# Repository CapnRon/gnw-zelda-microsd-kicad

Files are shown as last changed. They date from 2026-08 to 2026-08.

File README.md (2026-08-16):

# GnW-Zelda-MicroSD

A castellated-edge microSD interposer for the Game & Watch: The Legend of
Zelda console mod scene -- built as original KiCad artwork, informed by
existing community Gerber-only releases rather than copied from any of
them.

The board mates directly to the console's STM32 mainboard via a
7-position castellated edge (real 0.3x1.2mm SMD pad geometry, machined
flush by the board-edge mill -- this is the critical mechanical/electrical
mating surface, not an approximation) and carries an onboard RT9193-28GB
LDO regulating the console's raw ~4.2V battery rail down to a safe 2.8V
for the microSD card.

**This is a flex PCB**, not rigid: 2-layer, 1oz copper both sides on a
2mil (50.8um) polyimide core, 0.1408mm total board thickness.

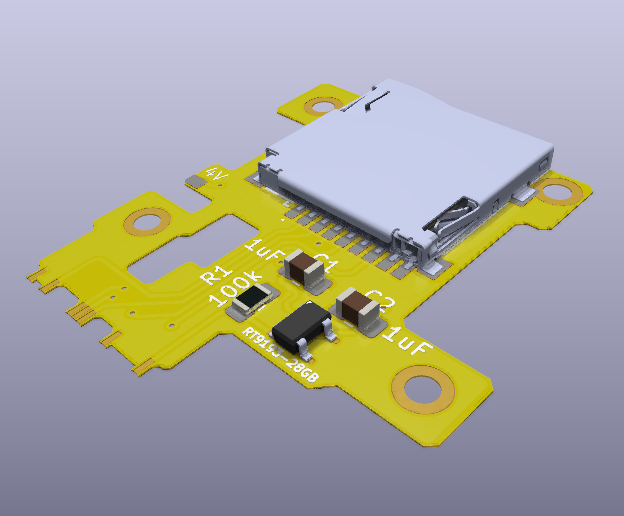
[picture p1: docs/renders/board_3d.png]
Populated board, 3D render


## Status

Working draft, not yet fab-verified on real hardware. Electrically clean
(0 unconnected nets, 0 shorts per `kicad-cli pcb drc`) with real routing
and filled ground pours on both copper layers. Remaining DRC output is
DFM-grade (clearances, drill sizes, silk overlap) -- normal manual-review
territory before ordering boards, not electrical faults. See
`docs/design-notes.md` for the full derivation, findings, and everything
still worth double-checking by hand in the KiCad GUI before fabrication.

## Commit history

- **Initial commit** -- the original reconstruction: schematic, PCB,
  footprints, and silkscreen rebuilt from scratch in KiCad from measured
  Gerber geometry (see Origin and attribution below). No third-party
  KiCad source files were used at this point -- every footprint was
  RE'd/approximated by hand from pad positions and sizes read off the
  Gerbers.
- **This commit** -- incorporates real assets from PrimoAngelo's native
  KiCad source (added as source material in the prior commit) now that
  he's confirmed as the known-good original author: J2 (microSD socket)
  and J3 (VBAT tab) were swapped from their RE'd/approximated footprints
  to his real `MSD1A`/`Pad_1x1_5` pad geometry, and a real STEP model was
  wired into U1 (RT9193 LDO). C1/C2/R1 now carry a second, real
  hand-solder-0805 footprint stacked at the same location as their
  original passive footprint, so either package size can be assembled.
  Also fixed a schematic/PCB reference-designator mismatch (J2/J3 and
  U1/U2 were swapped between the two files) and a batch of inconsistent
  net names left over from re-syncing the PCB against the schematic.

## Repository layout

```
hardware/         KiCad project (open GnW-Zelda-MicroSD.kicad_pro here)
production/       Gerbers + drill files (RS-274X, Excellon) + a zipped bundle
docs/             Design notes, top/bottom copper + 3D renders
source-material/  Original third-party source files this design descends
                   from, preserved for attribution/licence compliance --
                   see source-material/README.md
LICENSE           CERN-OHL-S v2 full text
NOTICE.md         Licensing rationale and attribution summary
```

## Circuit

- **U1** -- RT9193-28GB LDO. VIN <- raw battery (~4.2V) via the J1
  castellated edge; EN <- console GPIO (via J1); VOUT -> 2.8V microSD
  supply.
- **J2** -- microSD socket (SPI-mode wiring: CS/MOSI/MISO/CLK + VDD/GND),
  PrimoAngelo's real `MSD1A` footprint.
- **J1** -- 7-position castellated edge: GND, CS, MISO, CLK, MOSI, NC
  (spare), EN.
- **J3** -- castellated VBAT solder tab, PrimoAngelo's real `Pad_1x1_5`
  footprint (same machined-edge technique as J1) -- solders directly to
  the positive terminal of an external SMD capacitor.
- **R1** -- 100k pulldown holding the LDO disabled by default until the
  console GPIO actively enables it. Real hand-solder-0805 footprint
  stacked at the same location as the original RE'd footprint.
- **C1/C2** -- input/output decoupling for U1. Same dual-footprint
  stacking as R1 (0805 hand-solder on top of the original).
- **H1-H4** -- plated, electrically-isolated mounting pads (3.0mm pad /
  1.8mm drill), positioned to match the reference designs' mounting
  pattern.

## Origin and attribution

This design was reconstructed from precise geometry (board outline, pad
positions/sizes, net connectivity, and real copper routing) extracted
directly from Gerber-only community releases for the same G&W Zelda
microSD mod, tracing back through three generations of prior work:

- **Tim Schuerewegen** originated the project.
- **Hundshamer** picked it up and pushed it forward to its final form,
  `GNW-MICROSDx1-ZELDA-V3.4`. Used during reconstruction for
  cross-validation (confirmed identical castellated pinout via a
  different edge-connector pin-numbering scheme than PrimoAngelo's
  release) and as the source for the drilled-via castellation technique
  referenced during development.
- **PrimoAngelo** began his own work from Hundshamer's v3.4 design,
  producing `MicroSD_Zelda_FORO_JLC_FIX_V2 - NO_LOGO`, credited to him in
  its own back-silkscreen (visible in the source Gerbers). This is the
  primary geometric basis for this repo's outline, placement, and
  routing.

Everything in this repository (schematic, PCB, footprints, silkscreen)
was rebuilt from scratch in KiCad from measured geometry, not copied.
This reconstruction was completed before any contact with any of the
above. Afterward, both PrimoAngelo and Hundshamer were reached directly:
PrimoAngelo confirmed authorship and provided native KiCad source for
this design and a sibling Mario board; Hundshamer confirmed the lineage
back to Schuerewegen's original project in a friendly exchange, but had
no additional source material to contribute beyond what was already used
above. All original source material received is preserved under
`source-material/` for full provenance and CERN-OHL-S v2 compliance; see
`source-material/README.md` for the complete attribution chain and
`NOTICE.md` for the licensing rationale. Full credit to the original
designers for the mod itself; if you're one of them and want anything
here changed or removed, open an issue.

## License

CERN-OHL-S v2 (CERN Open Hardware Licence Version 2 - Strongly
Reciprocal). See [LICENSE](LICENSE) and [NOTICE.md](NOTICE.md).

## Building / opening

Requires KiCad 10. Open `hardware/GnW-Zelda-MicroSD.kicad_pro`.

Most custom parts (castellated connectors, exact-geometry footprints for
the LDO/passives) are embedded directly in the `.kicad_pcb`. J2 and J3
now use real footprints from PrimoAngelo's native library, referenced via
project-scoped libraries in `hardware/fp-lib-table` that point into
`source-material/` with `${KIPRJMOD}`-relative paths -- so the project
stays portable to any clone location, but `source-material/` must come
along with it. The schematic symbol library
(`hardware/gnw_zelda_microsd.kicad_sym`) is referenced the same way.

## Before ordering boards

- This is a hand-routed/reconstructed draft -- give it a real pass in the
  KiCad GUI (visual DRC review, silk/courtyard cleanup) before sending to
  a fab.
- The castellated edge geometry is the one dimension that matters most:
  verify pad pitch/size against your actual console board before
  committing to a fab run.
- No BOM/pick-and-place export included yet -- add before ordering
  assembly.

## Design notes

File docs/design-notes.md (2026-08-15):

# Design notes

## Goal

Build original KiCad artwork for a G&W Zelda microSD mod interposer,
using two existing Gerber-only community releases as dimensional/circuit
reference (not to be copied wholesale) -- see README for attribution.

## Reverse-engineering methodology

Both source projects are Gerber+drill exports only, no native KiCad
project files. Everything used here was extracted directly from the raw
RS-274X/Excellon data:

- **Board outline**: parsed all `D01`/`D02` draw commands from
  `*-Edge_Cuts.gbr`, chained line/arc segments into closed loops by
  matching endpoint coordinates (tolerance ~0.02mm). The
  `MicroSD_Zelda_FORO_JLC_FIX_V2` source outline resolved to two loops --
  the main board profile (81 segments) and a separate ~4x8mm cutout
  (15 segments) that turned out to be a real hole in the board, not a
  microSD card slot as first assumed.
- **Component placement & pinout**: KiCad's Gerber X2 export embeds
  `%TO.P,<ref>,<pin>,<name>%` and `%TO.N,<netname>%` attributes on every
  pad flash. Parsed these directly to get exact pad positions AND their
  real net/pin names -- no guessing required for pinout mapping.
- **Real pad geometry**: matched each pad flash to its active Gerber
  aperture (`%ADD..%` definitions) to get true pad shapes/sizes, rather
  than assuming standard library footprint dimensions. This caught a real
  early mistake -- initial footprints used guessed sizes (e.g. 0.7x0.5mm
  for the microSD socket signal pads) that were significantly smaller
  than the source's real 0.7x1.6mm pads.
- **Routing**: built a graph from every `F_Cu`/`B_Cu` trace segment
  (nodes = endpoints within ~0.02mm, edges = segments with their real
  layer/width), then ran Dijkstra between each net's known pad endpoints
  to extract the actual routed path -- including real F.Cu/B.Cu layer
  transitions -- rather than inventing new routing from scratch.

## The castellated edge (critical dimension)

The J1 connector butts directly against the console's STM32 mainboard --
this is the one piece of geometry that has to be exactly right, since a
wrong pitch/size means the board simply doesn't mate.

Confirmed via aperture lookup: **0.3mm x 1.2mm rectangular SMD pads**
(Gerber aperture `R,0.300000X1.200000`), each pad centered ~0.55mm in
from the true board edge so it slightly overhangs and gets milled flush
during fabrication -- this is the standard "castellated by copper
overhang" technique (as opposed to the alternative drilled-via
castellation method used by the other reference design, `GNW-MICROSDx1-
ZELDA-V3.4`, which drills a small via exactly on the edge line and relies
on the edge mill to bisect it).

7 contacts, confirmed identical function across both independently-
authored source designs (different edge-connector pin-numbering schemes,
same signals): **GND, CS, MISO, CLK, MOSI, NC (spare), EN**.

## J3: not a through-hole pad

Initially modeled J3 (the VBAT tap) as a simple 1mm through-hole point for
hand-soldering a flying lead. This was wrong. Its net auto-name in the
source Gerber (`Net-(J8-Pin_1)`) revealed it's actually an **8th
castellated contact** whose reference designator was stripped when the
source file was sanitized for public release (filename literally says
"NO_LOGO"). Confirmed via aperture lookup (`R,1.500000X1.500000`, a
1.5x1.5mm square pad) and via position -- it sits right at the board's
left edge with the same small mill-overhang pattern as the J1 contacts.
Rebuilt as a castellated square pad; per the design intent, it's meant to
solder directly to the positive terminal of an external SMD capacitor.

## Ground pour: the "covers everything until refilled" bug

`kicad-cli pcb export gerbers --check-zones` fills zones **transiently**
for that one export -- it never writes the computed fill back into the
`.kicad_pcb` file. Every earlier draft had a `(zone ...)` block with no
`filled_polygon` data at all, so opening the file fresh (or running DRC
without that flag) showed zero actual GND copper -- explaining a batch of
phantom "unconnected" ratsnest warnings that had nothing to do with the
routing itself.

Fixed by computing the fill directly (Shapely: zone boundary ∩ board
outline, minus every foreign-net pad/trace/via buffered by clearance) and
writing real `filled_polygon` data into both zone blocks. First attempt
at this had its own bug: a polygon with a hole (the board's real cutout,
see above) was emitted as two separate additive `filled_polygon` entries
-- an outer shape plus the hole's own boundary as a *second* filled shape
-- which paints solid copper right back over the hole instead of
excluding it. Fixed with the standard "keyhole" technique: cut a thin
slit from the hole out to the exterior boundary so the whole island is
one simple, hole-free ring.

## Routing bugs found during review

- A via for one net (VBAT_4V2) physically overlapped a crossing trace
  from a different net (SPI_CLK) on the same layer -- a real short. Root
  cause: two separately-computed net paths shared the same physical trunk
  (one was a redundant subset of the other); dropping the redundant path
  removed the overlapping via entirely.
- Missing vias at real F.Cu/B.Cu layer transitions, caused by not
  correctly tracking which endpoint was the true shared connection point
  between consecutive segments in a reversed-order path reconstruction
  (Dijkstra's predecessor-walk produces the path back-to-front).
- Explicit point-to-point GND traces were redundant once both layers had
  a real filled pour (every GND pad is F.Cu-only, so the F.Cu pour alone
  already connects them) -- removed entirely in favor of 1-2 stitching
  vias tying the two pours together, and verified those vias actually
  land inside real board copper (an earlier stitching via placement
  landed 0.93mm outside the true board outline -- "floating in space").

## Verification

`kicad-cli pcb drc` (KiCad 10.0.4, not the system default 9.0.8 --
version mismatch between the two installed CLIs caused a "Failed to load
board" red herring early on) confirms 0 unconnected items and 0
shorting_items on the current revision. Remaining ~46 violations are
DFM-grade (clearances, drill sizing, silk overlap) -- normal manual
cleanup, not electrical faults.

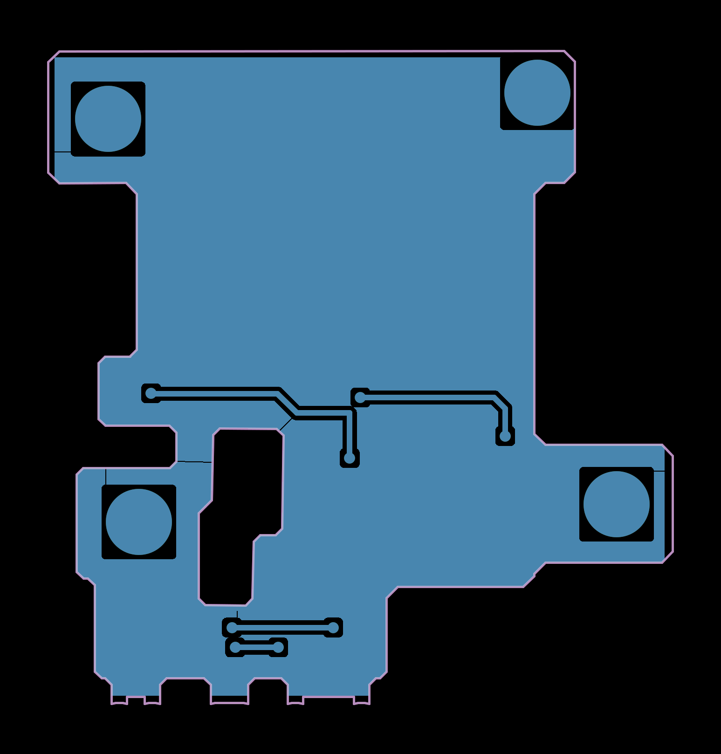
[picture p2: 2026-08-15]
docs/renders/bottom_copper.png

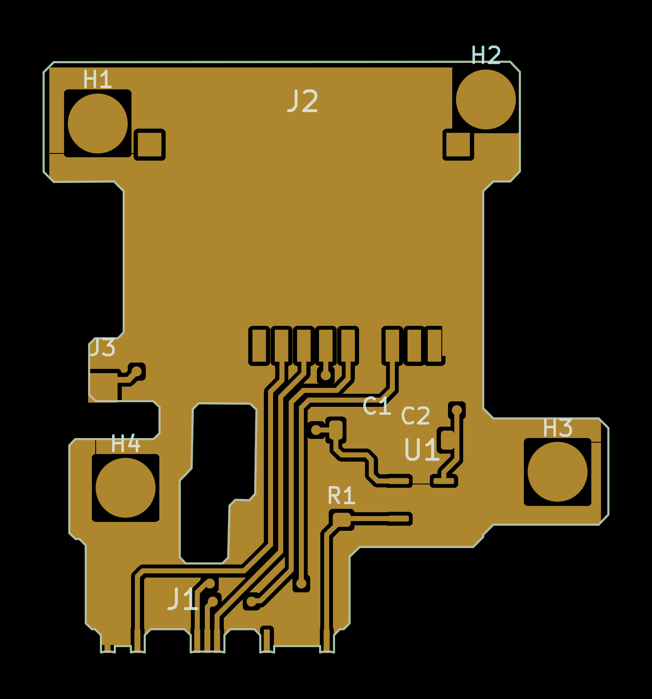
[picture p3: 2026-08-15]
docs/renders/top_copper.png

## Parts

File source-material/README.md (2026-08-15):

# Source material

This directory preserves, unmodified, every original design file this
project's attribution chain depends on -- kept here for provenance and
CERN-OHL-S v2 licence compliance (Covered Source must be made available;
see the repository [LICENSE](../LICENSE) and [NOTICE.md](../NOTICE.md)).

Each subdirectory contains the original archive exactly as received
(`*.zip`) plus its extracted contents (`extracted/`) for easier browsing
and diffing.

## Attribution chain

1. **Tim Schuerewegen** originated the Game & Watch Zelda microSD mod
   project this whole lineage descends from.
2. **Hundshamer** picked up the project and pushed it forward to its
   final form, `GNW-MICROSDx1-ZELDA-V3.4` -- see
   `gnw-microsd-zelda-v3.4-hundshamer/`.
3. **PrimoAngelo** began his own work from Hundshamer's v3.4 design,
   producing a derivative/alternate release -- see
   `microsd-zelda-gerbers-primoangelo/` (the Gerber-only file this
   repository was reverse-engineered from) and `kicad-zelda-primoangelo/`
   (PrimoAngelo's own native KiCad source for the same design, obtained
   later).
4. **This repository** was reverse-engineered from PrimoAngelo's
   Gerber-only release, then cross-validated against Hundshamer's v3.4
   design, before any contact with any of the above.

After that reconstruction was complete, both PrimoAngelo and Hundshamer
were contacted directly. PrimoAngelo confirmed authorship and provided
native KiCad source for this design and a sibling Mario board (see
below). Hundshamer confirmed the lineage back to Schuerewegen's original
project in a friendly exchange, but had no additional source material to
contribute beyond `GNW-MICROSDx1-ZELDA-V3.4`, already included here.

## `gnw-microsd-zelda-v3.4-hundshamer/`

`GnW_SD_v2.zip`, containing `GNW-MICROSDx1-ZELDA-V3.4` -- a Gerber/
Excellon-only release by **Hundshamer**, who picked up Tim Schuerewegen's
original Game & Watch Zelda microSD mod project and pushed it forward to
this, its final v3.4 form. Used during the original reverse-engineering
work for cross-validation (it confirmed the castellated pinout via a
different edge-connector pin-numbering scheme than PrimoAngelo's release)
and as the source for the drilled-via castellation technique referenced
in `docs/design-notes.md`.

## `microsd-zelda-gerbers-primoangelo/`

`MicroSD_Zelda_Final.zip`, containing
`MicroSD_Zelda_FORO_JLC_FIX_V2 - NO_LOGO` -- a Gerber/Excellon-only
release (no native KiCad project) credited to **PrimoAngelo** in its own
back-silkscreen, who began his own work from Hundshamer's v3.4 design
above. This is the file this repository's design was originally
reverse-engineered from, before any contact with any of the original
designers -- see `docs/design-notes.md` for the full reverse-engineering
methodology.

## `kicad-zelda-primoangelo/`

`KICAD_ZELDA_PrimoAngelo.zip`, containing the native KiCad project
(`MicroSD_Zelda_FORO_JLC_FIX_V2.kicad_pcb`/`.kicad_pro`) for the same
design above. Provided directly by PrimoAngelo **after** this
repository's reverse-engineering work was already complete, when the
designer was contacted for permission/attribution. Included here for full
provenance and licence compliance; this repository's own KiCad files were
not re-derived from it, since the reconstruction from Gerbers was already
finished and independently verified by the time this arrived.

## `kicad-mario-primoangelo/`

`KICAD_MARIO_PrimoAngelo.zip`, containing a native KiCad project
(`MicroSD_Mario_JLC_FIX_V3.kicad_pcb`/`.kicad_pro`) for a sibling
microSD mod board for a different Game & Watch title (Super Mario Bros.),
also by PrimoAngelo. Provided for the same reason as above, during the
same contact. Not a source for this repository's Zelda board -- included
purely for attribution/provenance and as reference material for anyone
working on the Mario variant in the future.

## `kicad-libs-primoangelo/`

`Libs.zip`, containing PrimoAngelo's own native KiCad footprint libraries
and 3D models used to build the designs above: `Impronte/` ("footprints",
Italian) with `Pad.pretty`/`_FG_Pad.pretty` (the castellated edge-contact
footprints, including `Pad_0_3x1_2.kicad_mod` -- matching this
repository's own independently-reconstructed 0.3x1.2mm castellated pad
geometry exactly, real confirmation the original reverse-engineering in
`docs/design-notes.md` got the geometry right) and `_FG_MicroSD.pretty`
(microSD socket/connector footprints), plus `Modelli_3D/` ("3D models")
with STEP models for the microSD socket and connector. Provided by
PrimoAngelo in a later contact, for the same attribution/provenance
reason as the items above -- not used to modify this repository's
existing (already-verified) footprints, included for completeness and as
a resource for future work (e.g. 3D visualization, mechanical checks).

## Licensing note

These files are third-party work, included here under the terms of
CERN-OHL-S v2 (the licence this repository itself is released under --
see [NOTICE.md](../NOTICE.md)). They are not covered by this repository's
own attribution disclaimers in `README.md`; refer to the original
designers for any use beyond what CERN-OHL-S v2 permits.

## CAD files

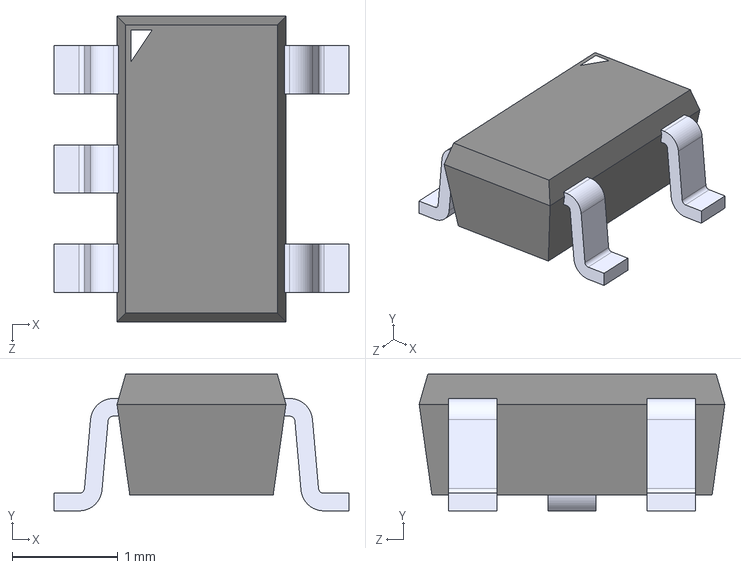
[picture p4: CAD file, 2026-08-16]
hardware/RT919333GB.STEP
2.79 x 1.30 x 2.90 mm

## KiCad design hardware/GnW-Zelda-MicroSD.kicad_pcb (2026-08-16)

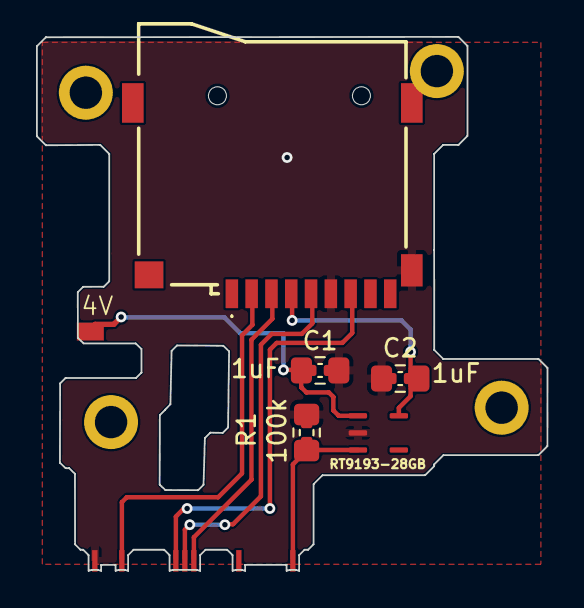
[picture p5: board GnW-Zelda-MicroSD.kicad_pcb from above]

Board: 2 copper layers, 28.4 x 29.7 mm, 11 parts (0 on the bottom side), 8 nets.

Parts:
C1, C2: 1uF; C_0402_1005Metric
H1, H2, H3, H4: MountingHole_3.0mm; MountingHole_Plated
J1: Castellated_Edge_7P
J2: MicroSD_Socket_TFP09; MSD1A
J3: Battery_Tap_2P; Pad_1x1_5
R1: 100k; R_0402_1005Metric
RT9193-28GB: RT9193-28GB; RT9193_exact

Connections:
EN_PA15: J1.7 (EN), R1.1, RT9193-28GB.3 (EN)
GND: C1.2, C2.2, J1.1 (GND), J2.6 (GND), J2.10 (SHIELD_GND), R1.2, RT9193-28GB.2 (GND)
SPI_CLK: J1.4 (CLK), J2.5 (SCLK)
SPI_CS: J1.2 (CS), J2.2 (CS)
SPI_MISO: J1.3 (MISO), J2.7 (DO)
SPI_MOSI: J1.5 (MOSI), J2.3 (DI)
VBAT_4V2: C1.1, J3.1 (VBAT_1), RT9193-28GB.1 (VIN)
VDD_SD_2V8: C2.1, J2.4 (VDD), RT9193-28GB.5 (VOUT)

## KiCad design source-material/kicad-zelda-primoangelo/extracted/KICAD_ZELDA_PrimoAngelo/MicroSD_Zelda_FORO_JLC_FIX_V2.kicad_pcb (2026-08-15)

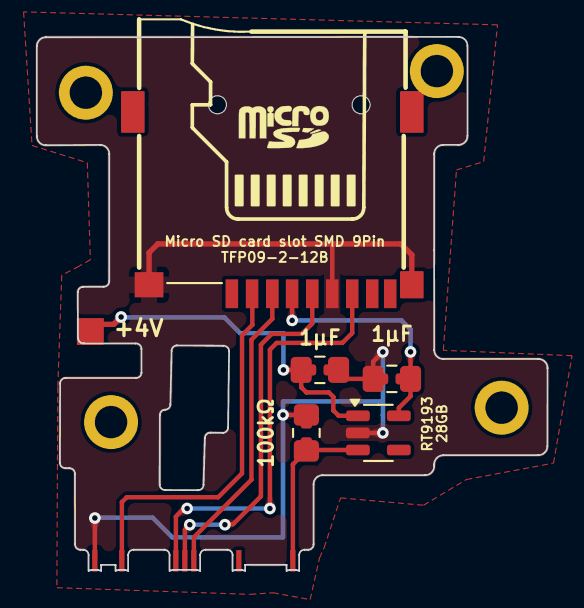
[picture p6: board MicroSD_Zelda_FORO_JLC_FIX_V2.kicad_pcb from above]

Board: 2 copper layers, 28.4 x 29.7 mm, 21 parts (1 on the bottom side), 8 nets.

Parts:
1µF, 1µF#2: 1u; C_0402_1005Metric_Pad0.74x0.62mm_HandSolder
100kΩ: 100k; R_0402_1005Metric_Pad0.72x0.64mm_HandSolder
C2, C4: 1u; C_0805_2012Metric_Pad1.18x1.45mm_HandSolder
H1, H2, H3, H4: MountingHole; MountingHole_1.7x3mm
J9: TFP09-2-12B
Pin77, Pin83, Pin88, Pin89, Pin90, Pin96, Pin99: PadMicro; Pad_0_3x1_2
R2: 100k; R_0805_2012Metric_Pad1.20x1.40mm_HandSolder
RT9193: RT9193-28GB; SOT-23-5
Ref**: Val**; drawing
Ref**#2: Val**; drawing

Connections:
/CLK: J9.5 (CLK), Pin89.1
/CS: J9.2 (CS), Pin96.1
/EN_LDO: 100kΩ.1, Pin77.1, R2.1, RT9193.3 (EN)
/MISO: J9.7 (MISO), Pin90.1
/MOSI: J9.3 (MOSI), Pin88.1
GND: 1µF.1, 1µF#2.1, 100kΩ.2, C2.1, C4.1, J9.6 (VSS), J9.10 (SHIELD), Pin99.1, R2.2, RT9193.2 (GND)
unnamed: 1µF.2, C2.2, RT9193.1 (IN)
unnamed: 1µF#2.2, C4.2, J9.4 (VDD), RT9193.5 (OUT)

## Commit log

2026-08-15 Initial commit: GnW Zelda microSD interposer
    Original KiCad artwork for a castellated-edge microSD mod board for the
    Game & Watch: The Legend of Zelda, reverse-engineered from prior
    Gerber-only community releases. Includes production Gerbers, design
    notes, and full third-party source-material attribution chain
    (Schuerewegen -> Hundshamer -> PrimoAngelo) under CERN-OHL-S v2.
    [GNW-MICROSDx1-ZELDA-V3.4-B_Cu.gbr, GNW-MICROSDx1-ZELDA-V3.4-B_Mask.gbr, GNW-MICROSDx1-ZELDA-V3.4-B_Paste.gbr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]
2026-08-15 Add PrimoAngelo's native KiCad footprint/3D-model libraries as source material
    Third batch of source files from PrimoAngelo (footprints + STEP models used
    to build his original design), preserved under source-material/ for
    attribution/provenance per CERN-OHL-S v2, same as prior contributions.
2026-08-16 Swap J2/J3/U1 to PrimoAngelo's real footprints, fix ref-designator and net-naming bugs
    J2 (microSD socket) and J3 (VBAT tab) now use real MSD1A/Pad_1x1_5
    geometry from PrimoAngelo's native KiCad library instead of RE'd
    approximations; U1 gets a real RT9193 STEP model. C1/C2/R1 get a second,
    real hand-solder-0805 footprint stacked at their original location for
    package-size flexibility.
    Also fixes: schematic/PCB reference-designator swap (J2/J3, U1/U2), a
    batch of inconsistent net names left over from re-syncing the PCB from
    schematic (local net labels converted to global to prevent recurrence),
    and 8 undersized vias failing min-hole-size DRC.
    [GnW-Zelda-MicroSD.kicad_pcb, GnW-Zelda-MicroSD.kicad_sch, RT919333GB.STEP]
2026-08-16 Clean up schematic layout and silkscreen
    Manual schematic relayout (wires/symbols, no connectivity changes --
    component roster and net topology unchanged, verified via ERC/DRC). PCB
    silkscreen cleanup: R1/C1/C2 values moved from F.Fab to F.SilkS so
    they're visible on the physical board, U1's reference text replaced with
    its part number (RT9193-28GB) since it's the board's only IC and "U1"
    isn't descriptive, and a "4V" label added near the VBAT tap (J3).
    [GnW-Zelda-MicroSD.kicad_pcb, GnW-Zelda-MicroSD.kicad_sch]
2026-08-16 Real flex stackup, fix 3D model paths, add board render to README
    Board reconfigured to a real 2-layer flex stackup (1oz/1oz copper,
    2mil/50.8um polyimide core, 0.1408mm total) instead of the placeholder
    rigid 1.6mm default. Fixed J2's (MSD1A) 3D model reference, which had
    broken from a directory move and was also hardcoded to an absolute
    Windows path -- repointed to a portable ${KIPRJMOD}-relative path
    matching every other model reference. Added a populated 3D render to the
    README and updated the intro to state the flex construction.
    [GnW-Zelda-MicroSD.kicad_pcb]
